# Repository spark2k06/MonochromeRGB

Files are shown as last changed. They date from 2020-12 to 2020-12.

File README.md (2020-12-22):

# MonochromeRGB

MonochromeRGB is a project to enjoy the charm of those monochrome monitors of the time but in the current video systems, those with VGA or SCART inputs. Where this product is most enjoyed is in CRT monitors, where the feeling of an old monitor is much more realistic.

https://hackaday.io/project/176201-monochromergb

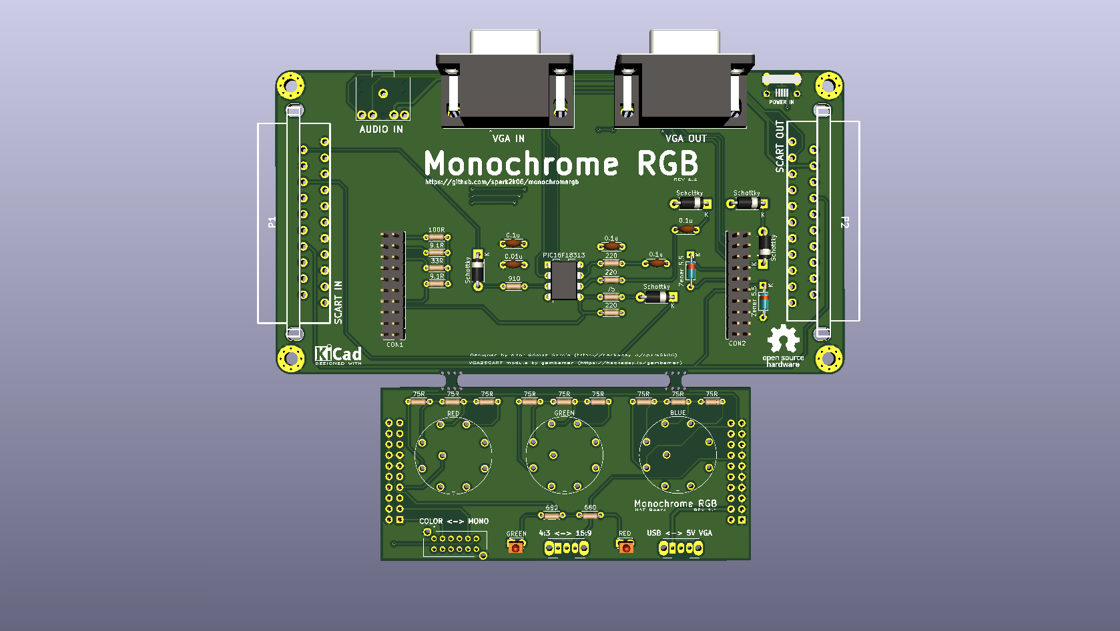
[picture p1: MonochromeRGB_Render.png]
Render


Coworked with gambaman, when integrating the VGA2SCART module: 

https://hackaday.io/project/165634-the-ultimate-vga-to-scart-adapter

open hardware facts

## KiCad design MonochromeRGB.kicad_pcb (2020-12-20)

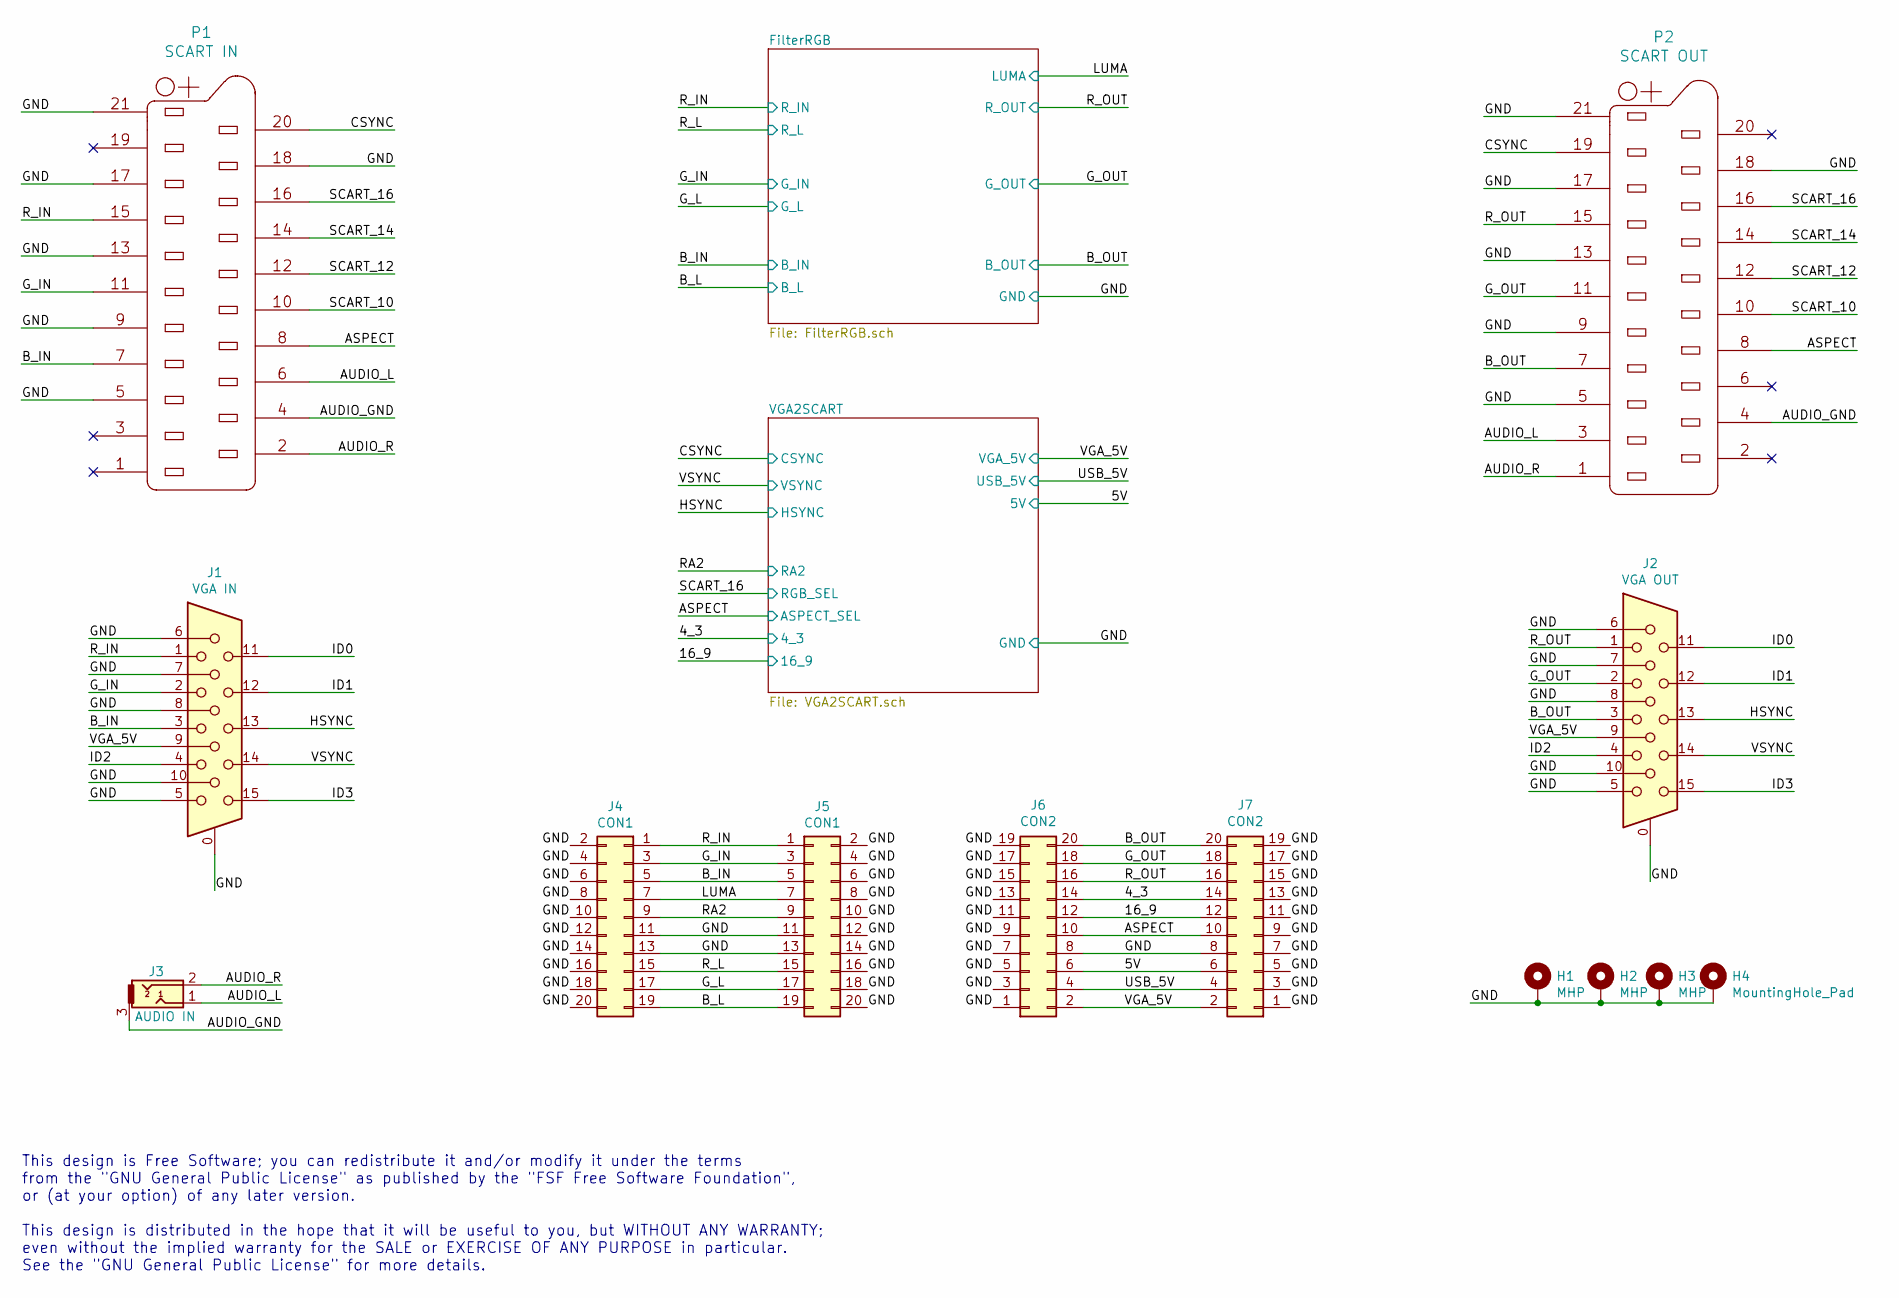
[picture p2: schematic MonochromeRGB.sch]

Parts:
H1, H2, H3: MHP; MountingHole_3.2mm_M3_Pad_Via
H4: MountingHole_Pad; MountingHole_3.2mm_M3_Pad_Via
J1: VGA IN; DSUB-15-HD_Female_Horizontal_P2.29x1.98mm_EdgePinOffset8.35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
J2: VGA OUT; DSUB-15-HD_Female_Horizontal_P2.29x1.98mm_EdgePinOffset8.35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
J3: AUDIO IN; SJ1-3523N-MvK
J4: CON1; PinHeader_2x10_P2.54mm_Vertical
J5: CON1; PinSocket_2x10_P2.54mm_Vertical
J6: CON2; PinHeader_2x10_P2.54mm_Vertical
J7: CON2; PinSocket_2x10_P2.54mm_Vertical
P1: SCART IN; SCART
P2: SCART OUT; SCART

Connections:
/4_3: J6.14, J7.14; also elsewhere on the board
/5V: J6.6, J7.6; also elsewhere on the board
/16_9: J6.12, J7.12; also elsewhere on the board
/ASPECT: J6.10, J7.10, P1.8, P2.8; also elsewhere on the board
/AUDIO_GND: J3.3, P1.4, P2.4
/AUDIO_L: J3.1, P1.6, P2.3
/AUDIO_R: J3.2, P1.2, P2.1
/B_IN: J1.3, J4.5, J5.5, P1.7; also elsewhere on the board
/B_L: J4.19, J5.19; also elsewhere on the board
/B_OUT: J2.3, J6.20, J7.20, P2.7; also elsewhere on the board
/CSYNC: P1.20, P2.19; also elsewhere on the board
/GND: H1.1, H2.1, H3.1, H4.1, J1.0, J1.5, J1.6, J1.7, J1.8, J1.10, J2.0, J2.5, J2.6, J2.7, J2.8, J2.10, J4.2, J4.4, J4.6, J4.8, J4.10, J4.11, J4.12, J4.13, J4.14, J4.16, J4.18, J4.20, J5.2, J5.4, J5.6, J5.8, J5.10, J5.11, J5.12, J5.13, J5.14, J5.16, J5.18, J5.20, J6.1, J6.3, J6.5, J6.7, J6.8, J6.9, J6.11, J6.13, J6.15, J6.17, J6.19, J7.1, J7.3, J7.5, J7.7, J7.8, J7.9, J7.11, J7.13, J7.15, J7.17, J7.19, P1.5, P1.9, P1.13, P1.17, P1.18, P1.21, P2.5, P2.9, P2.13, P2.17, P2.18, P2.21; also elsewhere on the board
/G_IN: J1.2, J4.3, J5.3, P1.11; also elsewhere on the board
/G_L: J4.17, J5.17; also elsewhere on the board
/G_OUT: J2.2, J6.18, J7.18, P2.11; also elsewhere on the board
/HSYNC: J1.13, J2.13; also elsewhere on the board
/ID0: J1.11, J2.11
/ID1: J1.12, J2.12
/ID2: J1.4, J2.4
/ID3: J1.15, J2.15
/LUMA: J4.7, J5.7; also elsewhere on the board
/RA2: J4.9, J5.9; also elsewhere on the board
/R_IN: J1.1, J4.1, J5.1, P1.15; also elsewhere on the board
/R_L: J4.15, J5.15; also elsewhere on the board
/R_OUT: J2.1, J6.16, J7.16, P2.15; also elsewhere on the board
/SCART_10: P1.10, P2.10
/SCART_12: P1.12, P2.12
/SCART_14: P1.14, P2.14
/SCART_16: P1.16, P2.16; also elsewhere on the board
/USB_5V: J6.4, J7.4; also elsewhere on the board
/VGA_5V: J1.9, J2.9, J6.2, J7.2; also elsewhere on the board
/VSYNC: J1.14, J2.14; also elsewhere on the board

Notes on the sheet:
This design is Free Software; you can redistribute it and/or modify it under the terms from the "GNU General Public License" as published by the "FSF Free Software Foundation", or (at your option) of any later version. This design is distributed in the hope that it will be useful to you, but WITHOU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

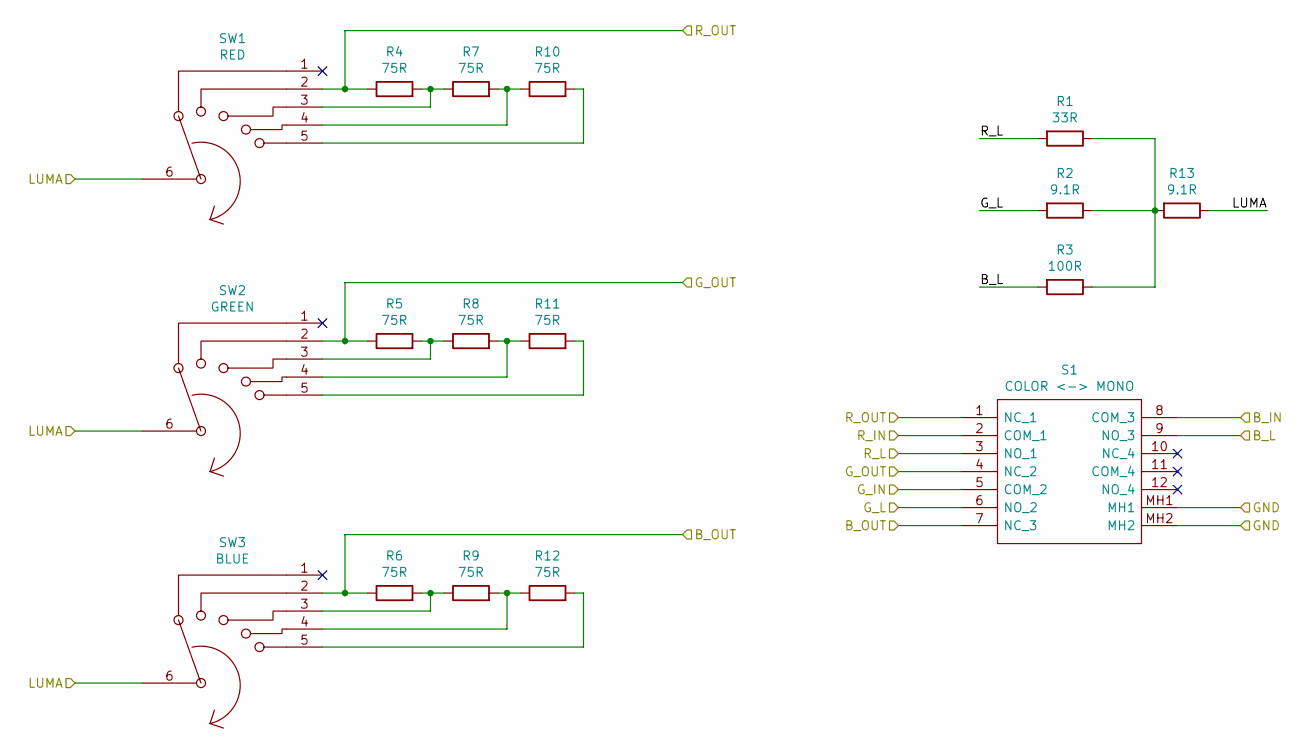
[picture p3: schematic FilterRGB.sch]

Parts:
R1: 33R; R_Axial_DIN0204_L3.6mm_D1.6mm_P5.08mm_Horizontal
R2, R13: 9.1R; R_Axial_DIN0204_L3.6mm_D1.6mm_P5.08mm_Horizontal
R3: 100R; R_Axial_DIN0204_L3.6mm_D1.6mm_P5.08mm_Horizontal
R4, R5, R6, R7, R8, R9, R10, R11, R12: 75R; R_Axial_DIN0204_L3.6mm_D1.6mm_P5.08mm_Horizontal
S1: COLOR <-> MONO; EG4208A; Mouser Part Number 612-EG4208A
SW1: RED; Rotary_Switch_1P5
SW2: GREEN; Rotary_Switch_1P5
SW3: BLUE; Rotary_Switch_1P5

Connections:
/B_IN: S1.8 (COM_3); also elsewhere on the board
/B_L: R3.2, S1.9 (NO_3); also elsewhere on the board
/B_OUT: R6.1, S1.7 (NC_3), SW3.2; also elsewhere on the board
/GND: S1.MH1, S1.MH2; also elsewhere on the board
/G_IN: S1.5 (COM_2); also elsewhere on the board
/G_L: R2.2, S1.6 (NO_2); also elsewhere on the board
/G_OUT: R5.1, S1.4 (NC_2), SW2.2; also elsewhere on the board
/LUMA: R13.1, SW1.6, SW2.6, SW3.6; also elsewhere on the board
/R_IN: S1.2 (COM_1); also elsewhere on the board
/R_L: R1.2, S1.3 (NO_1); also elsewhere on the board
/R_OUT: R4.1, S1.1 (NC_1), SW1.2; also elsewhere on the board
unnamed: R1.1, R2.1, R3.1, R13.2
unnamed: R4.2, R7.1, SW1.3
unnamed: R5.2, R8.1, SW2.3
unnamed: R6.2, R9.1, SW3.3
unnamed: R7.2, R10.1, SW1.4
unnamed: R10.2, SW1.5
unnamed: R8.2, R11.1, SW2.4
unnamed: R11.2, SW2.5
unnamed: R9.2, R12.1, SW3.4
unnamed: R12.2, SW3.5

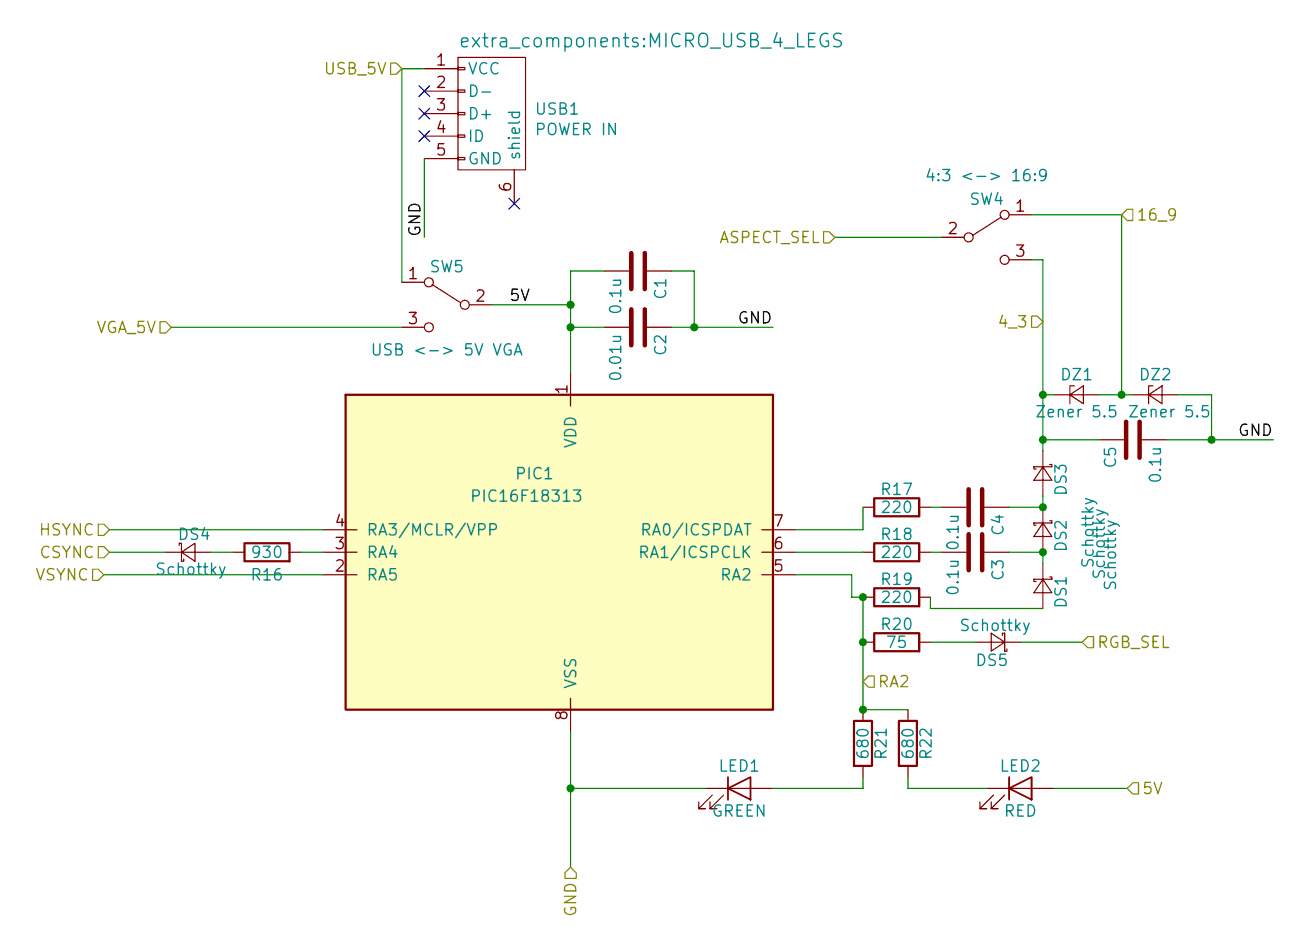
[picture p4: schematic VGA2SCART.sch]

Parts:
C1, C3, C4, C5: 0.1u; C_Disc_D4.3mm_W1.9mm_P5.00mm
C2: 0.01u; C_Disc_D4.3mm_W1.9mm_P5.00mm
DS1, DS2, DS3, DS4, DS5: Schottky; D_DO-41_SOD81_P7.62mm_Horizontal
DZ1, DZ2: Zener 5.5; D_DO-35_SOD27_P7.62mm_Horizontal
LED1: GREEN; LED_D1.8mm_W3.3mm_H2.4mm
LED2: RED; LED_D1.8mm_W3.3mm_H2.4mm
PIC1: PIC16F18313; DIP-8_W7.62mm
R16: 930; R_Axial_DIN0204_L3.6mm_D1.6mm_P5.08mm_Horizontal
R17, R18, R19: 220; R_Axial_DIN0204_L3.6mm_D1.6mm_P5.08mm_Horizontal
R20: 75; R_Axial_DIN0204_L3.6mm_D1.6mm_P5.08mm_Horizontal
R21, R22: 680; R_Axial_DIN0204_L3.6mm_D1.6mm_P5.08mm_Horizontal
SW4: 4:3 <-> 16:9; SW_CuK_OS102011MA1QN1_SPDT_Angled
SW5: USB <-> 5V VGA; SW_CuK_OS102011MA1QN1_SPDT_Angled
USB1: POWER IN; MICRO_USB_4_LEGS

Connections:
/4_3: C5.1, DS3.1 (K), DZ1.1 (K), SW4.3 (C); also elsewhere on the board
/5V: C1.2, C2.2, LED2.2 (A), PIC1.1 (VDD), SW5.2 (B); also elsewhere on the board
/16_9: DZ1.2 (A), DZ2.1 (K), SW4.1 (A); also elsewhere on the board
/ASPECT: SW4.2 (B); also elsewhere on the board
/CSYNC: DS4.1 (K); also elsewhere on the board
/GND: C1.1, C2.1, C5.2, DZ2.2 (A), LED1.1 (K), PIC1.8 (VSS), USB1.5 (GND); also elsewhere on the board
/HSYNC: PIC1.4 (RA3/MCLR/VPP); also elsewhere on the board
/RA2: PIC1.5 (RA2), R19.1, R20.1, R21.1, R22.1; also elsewhere on the board
/SCART_16: DS5.1 (K); also elsewhere on the board
/USB_5V: SW5.1 (A), USB1.1 (VCC); also elsewhere on the board
/VGA_5V: SW5.3 (C); also elsewhere on the board
/VSYNC: PIC1.2 (RA5); also elsewhere on the board
unnamed: C3.1, DS1.1 (K), DS2.2 (A)
unnamed: C3.2, R18.2
unnamed: C4.1, DS2.1 (K), DS3.2 (A)
unnamed: C4.2, R17.2
unnamed: DS1.2 (A), R19.2
unnamed: DS4.2 (A), R16.1
unnamed: DS5.2 (A), R20.2
unnamed: LED1.2 (A), R21.2
unnamed: LED2.1 (K), R22.2
unnamed: PIC1.3 (RA4), R16.2
unnamed: PIC1.6 (RA1/ICSPCLK), R18.1
unnamed: PIC1.7 (RA0/ICSPDAT), R17.1

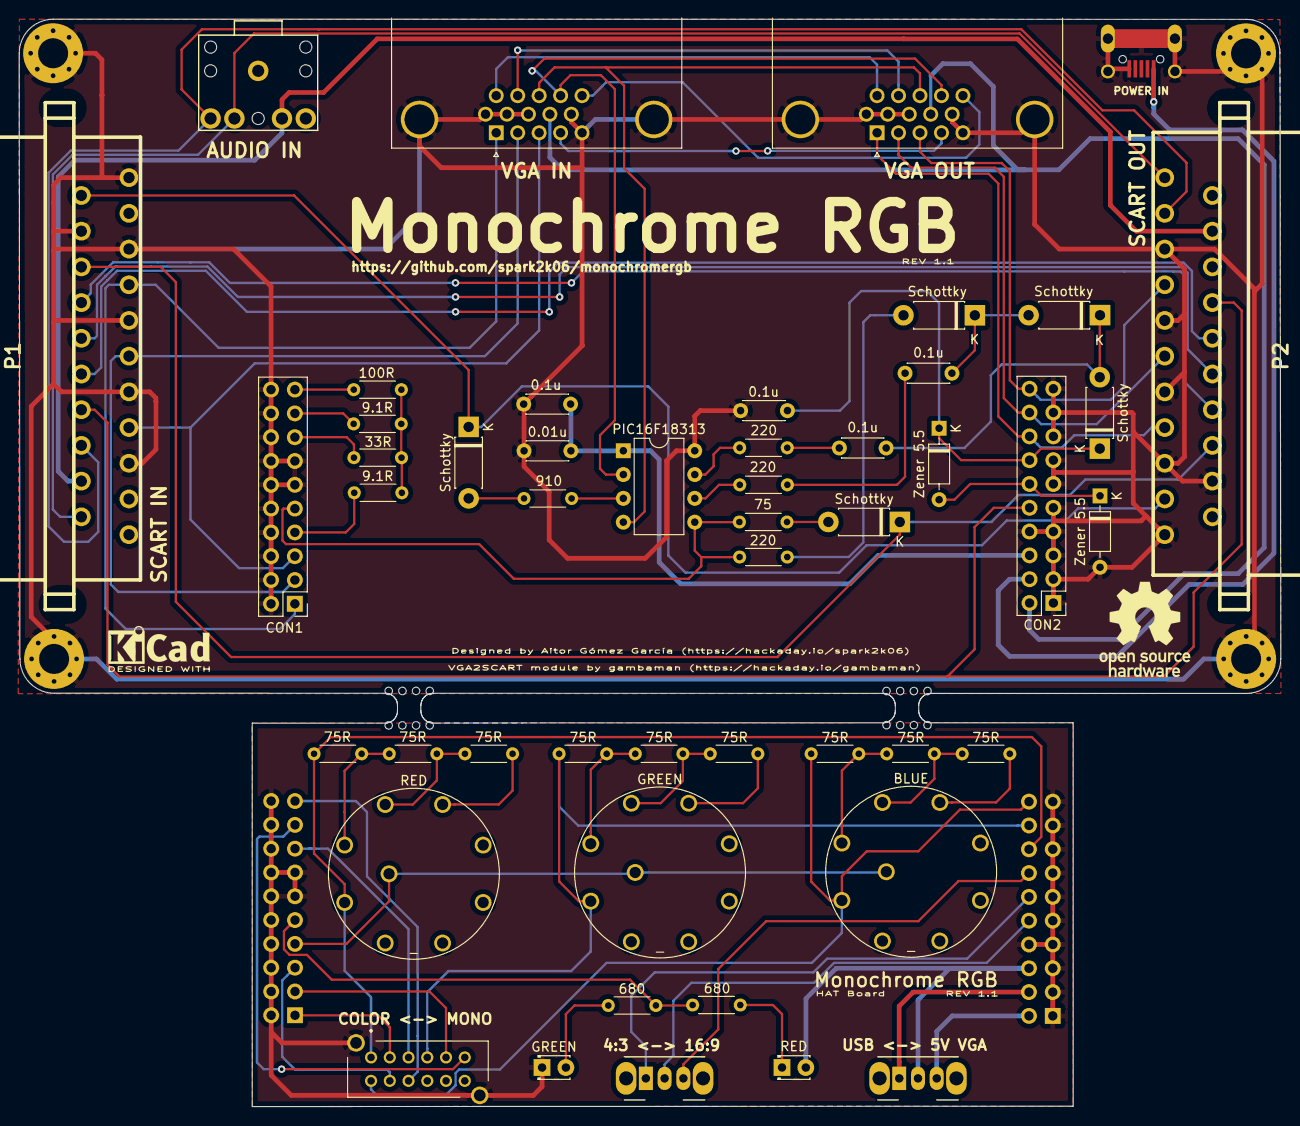
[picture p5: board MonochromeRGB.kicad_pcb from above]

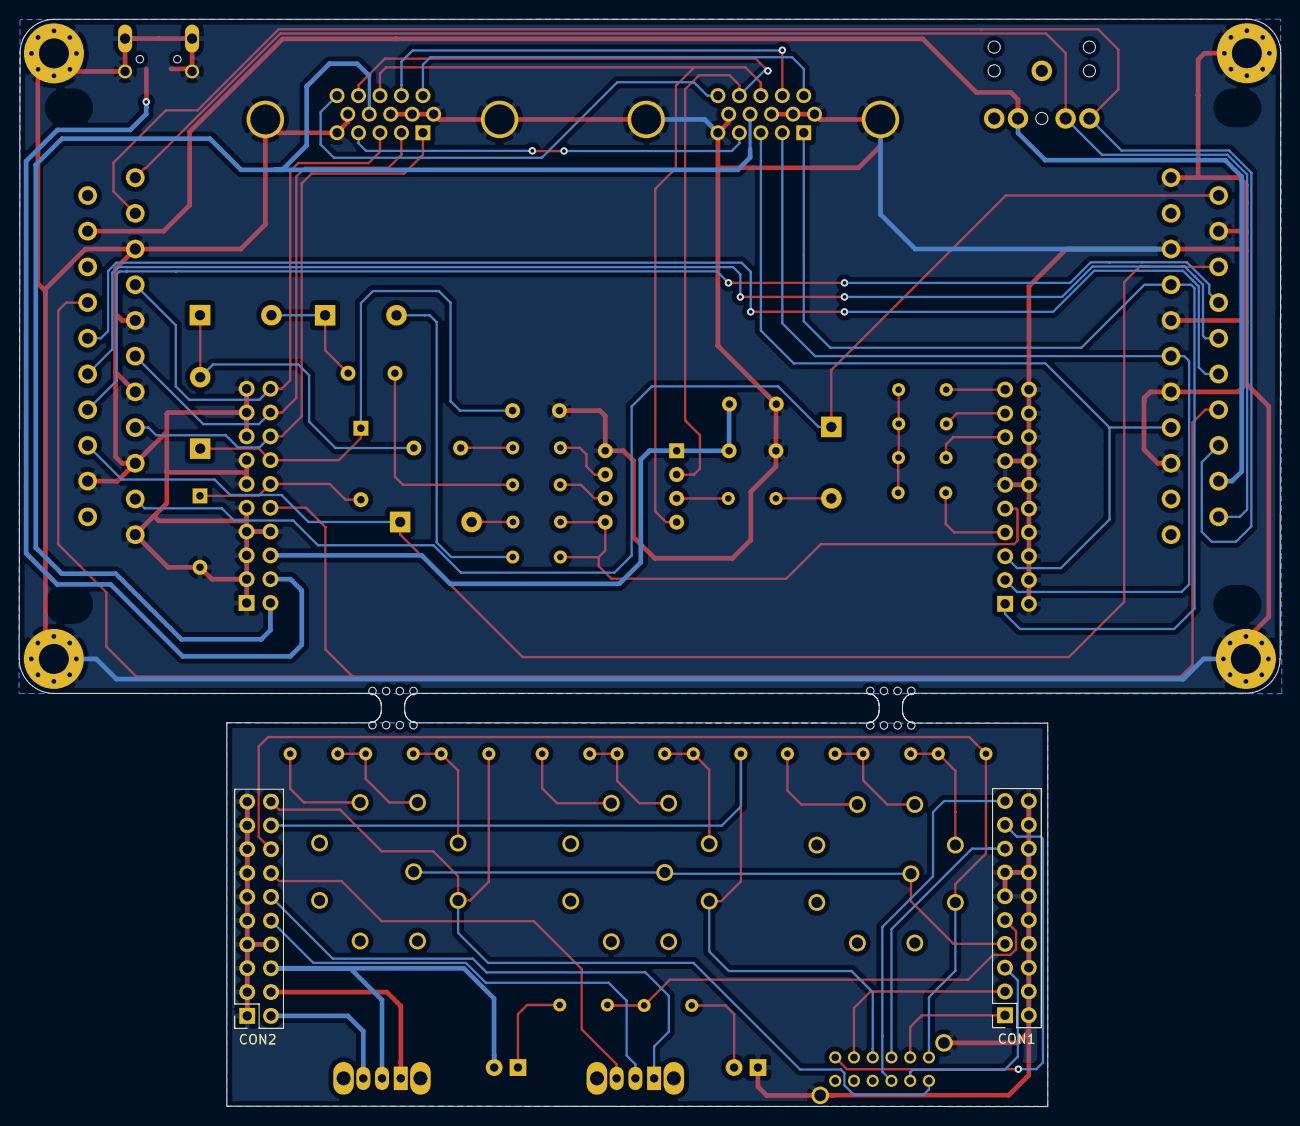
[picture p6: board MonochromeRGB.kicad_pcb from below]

Board: 2 copper layers, 134.6 x 116.0 mm, 55 parts (2 on the bottom side), 54 nets.

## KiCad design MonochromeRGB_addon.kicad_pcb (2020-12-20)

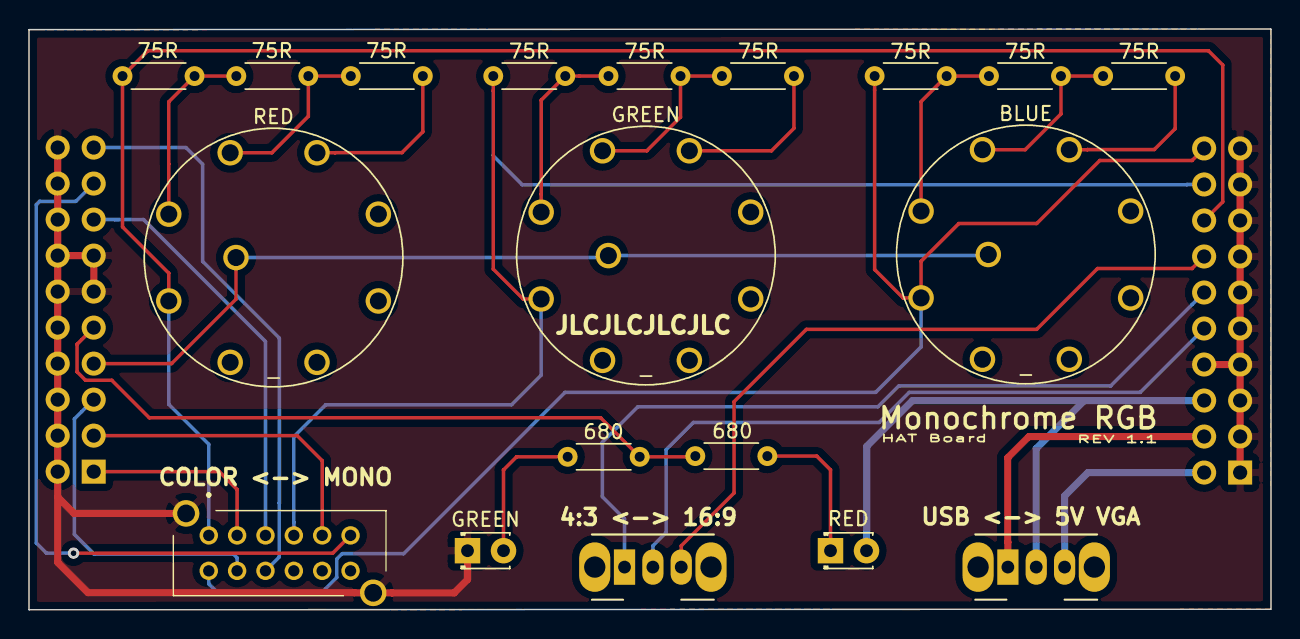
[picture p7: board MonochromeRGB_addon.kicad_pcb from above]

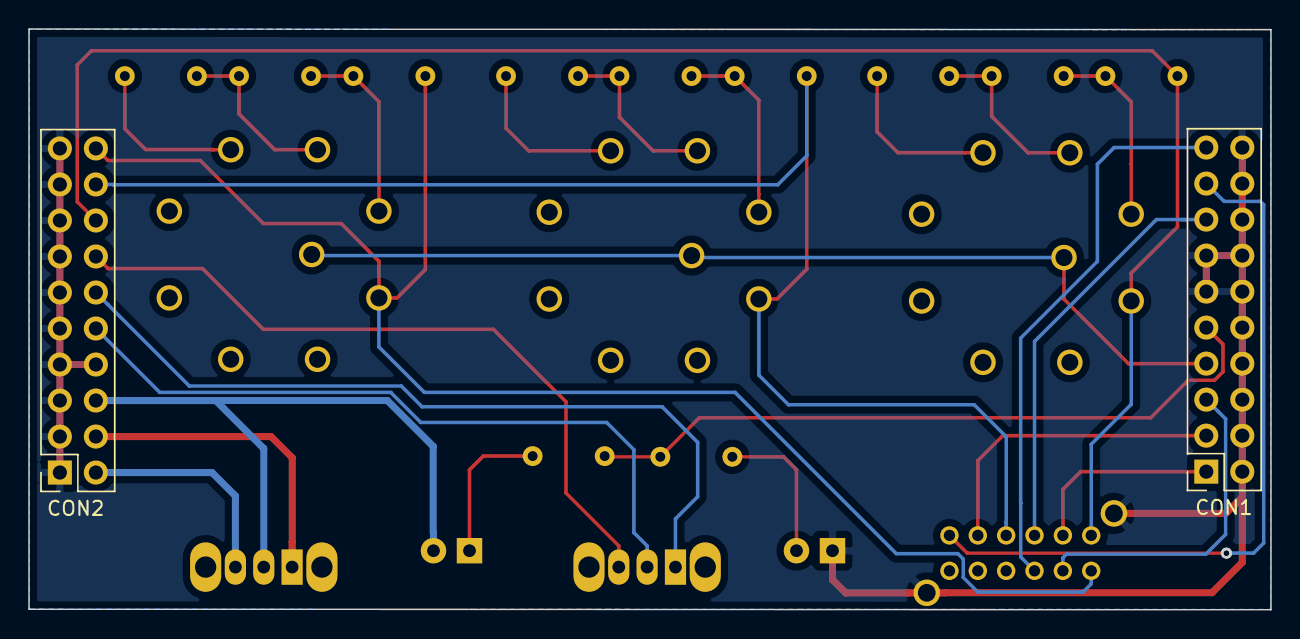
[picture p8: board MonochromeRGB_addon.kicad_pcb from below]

Board: 2 copper layers, 87.6 x 41.0 mm, 21 parts (2 on the bottom side), 29 nets.

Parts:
J5: CON1; PinSocket_2x10_P2.54mm_Vertical
J7: CON2; PinSocket_2x10_P2.54mm_Vertical
LED1: GREEN; LED_D1.8mm_W3.3mm_H2.4mm
LED2: RED; LED_D1.8mm_W3.3mm_H2.4mm
R4, R5, R6, R7, R8, R9, R10, R11, R12: 75R; R_Axial_DIN0204_L3.6mm_D1.6mm_P5.08mm_Horizontal
R21, R22: 680; R_Axial_DIN0204_L3.6mm_D1.6mm_P5.08mm_Horizontal
S1: COLOR <-> MONO; EG4208A
SW1: RED; Rotary_Switch_1P5
SW2: GREEN; Rotary_Switch_1P5
SW3: BLUE; Rotary_Switch_1P5
SW4: 4:3 <-> 16:9; SW_CuK_OS102011MA1QN1_SPDT_Angled
SW5: USB <-> 5V VGA; SW_CuK_OS102011MA1QN1_SPDT_Angled

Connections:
/4_3: J7.14, SW4.3
/5V: J7.6, LED2.2, SW5.2
/16_9: J7.12, SW4.1
/ASPECT: J7.10, SW4.2
/B_IN: J5.5, S1.8
/B_L: J5.19, S1.9
/B_OUT: J7.20, R6.1, S1.7, SW3.2
/GND: J5.2, J5.4, J5.6, J5.8, J5.10, J5.11, J5.12, J5.13, J5.14, J5.16, J5.18, J5.20, J7.1, J7.3, J7.5, J7.7, J7.8, J7.9, J7.11, J7.13, J7.15, J7.17, J7.19, LED1.1, S1.MH1, S1.MH2
/G_IN: J5.3, S1.5
/G_L: J5.17, S1.6
/G_OUT: J7.18, R5.1, S1.4, SW2.2
/LUMA: J5.7, SW1.6, SW2.6, SW3.6
/RA2: J5.9, R21.1, R22.1
/R_IN: J5.1, S1.2
/R_L: J5.15, S1.3
/R_OUT: J7.16, R4.1, S1.1, SW1.2
/USB_5V: J7.4, SW5.1
/VGA_5V: J7.2, SW5.3
unnamed: LED1.2, R21.2
unnamed: LED2.1, R22.2
unnamed: R4.2, R7.1, SW1.3
unnamed: R5.2, R8.1, SW2.3
unnamed: R6.2, R9.1, SW3.3
unnamed: R7.2, R10.1, SW1.4
unnamed: R10.2, SW1.5
unnamed: R8.2, R11.1, SW2.4
unnamed: R11.2, SW2.5
unnamed: R9.2, R12.1, SW3.4
unnamed: R12.2, SW3.5

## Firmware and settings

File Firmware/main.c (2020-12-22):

/* VGA sync to SCART composite video sync generator
 * Copyright (C) 2019 David Guerrero
 *
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
 * THE SOFTWARE IS PROVIDED "AS IS", WITHOUT WARRANTY OF ANY KIND, EXPRESS OR
 * IMPLIED, INCLUDING BUT NOT LIMITED TO THE WARRANTIES OF MERCHANTABILITY,
 * FITNESS FOR A PARTICULAR PURPOSE AND NONINFRINGEMENT. IN NO EVENT SHALL THE
 * AUTHORS OR COPYRIGHT HOLDERS BE LIABLE FOR ANY CLAIM, DAMAGES OR OTHER
 * LIABILITY, WHETHER IN AN ACTION OF CONTRACT, TORT OR OTHERWISE, ARISING FROM,
 * OUT OF OR IN CONNECTION WITH THE SOFTWARE OR THE USE OR OTHER DEALINGS IN
 * THE SOFTWARE.
 */

#include <pic.h>
#include <stdint.h>

// CONFIG1
#pragma config FEXTOSC = OFF // FEXTOSC External Oscillator mode Selection bits (Oscillator not enabled)
#pragma config RSTOSC = HFINT32 // Power-up default value for COSC bits (HFINTOSC with 2x PLL (32MHz))
#pragma config CLKOUTEN = OFF // Clock Out Enable bit (CLKOUT function is enabled; FOSC/4 clock appears at OSC2)
#pragma config CSWEN = ON // Clock Switch Enable bit (Writing to NOSC and NDIV is allowed)
#pragma config FCMEN = ON // Fail-Safe Clock Monitor Enable (Fail-Safe Clock Monitor is enabled)

// CONFIG2
#pragma config MCLRE = OFF // Master Clear Enable bit (MCLR/VPP pin function is digital input; MCLR internally disabled; Weak pull-up under control of port pin's WPU control bit.)
#pragma config PWRTE = ON // Power-up Timer Enable bit (PWRT enabled)
#pragma config WDTE = OFF // Watchdog Timer Enable bits (WDT disabled; SWDTEN is ignored)
#pragma config LPBOREN = OFF // Low-power BOR enable bit (ULPBOR disabled)
#pragma config BOREN = ON // Brown-out Reset Enable bits (Brown-out Reset enabled, SBOREN bit ignored)
#pragma config BORV = HIGH // Brown-out Reset Voltage selection bit (Brown-out voltage (Vbor) set to 2.45V)
#pragma config PPS1WAY = OFF // PPSLOCK bit One-Way Set Enable bit (The PPSLOCK bit can be cleared and set only once; PPS registers remain locked after one clear/set cycle)
#pragma config STVREN = ON // Stack Overflow/Underflow Reset Enable bit (Stack Overflow or Underflow will cause a Reset)
#pragma config DEBUG = OFF // Debugger enable bit (Background debugger disabled)


// CONFIG3
#pragma config WRT = OFF // User NVM self-write protection bits (Write protection off)
#pragma config LVP = OFF // Low Voltage Programming Enable bit (Low voltage programming enabled. MCLR/VPP pin function is MCLR. MCLRE configuration bit is ignored.)

// CONFIG4
#pragma config CP = OFF // User NVM Program Memory Code Protection bit (User NVM code protection disabled)
#pragma config CPD = OFF // Data NVM Memory Code Protection bit (Data NVM code protection disabled)

#define _XTAL_FREQ 32000000 //system clock frequency in hertzs
#define wave_FREQ 160000 //desired output wave frequency in hertzs
#define NCO_increment ((((uint32_t)wave_FREQ)<<11)/15625)//NCO clock will be HFINTOSC (16 MHz))
#define hsync_FREQ  15734 //Hsync nominal frequency in hertzs
#define hsync_normal_value LC1G3POL
#define vsync_pulsed_value LC1G1POL
#define hsync_value RA3
#define hsync_RA_number 3
#define vsync_value RA5
#define vsync_RA_number 5
#define enable RA2
#define enable_RA_number 2
#define cynscPPS RA4PPS
#define csync_RA_number 4
#define countdown_duration 740

void main(void)
{
    PORTA=0;
    TRISA=(1 << vsync_RA_number) | (1 << hsync_RA_number); //vsync and hsync input, everything else output
    ANSELA=0; //no analog inputs
    
    NCO1CLK=0;//NCO input clock is FINTOSC (16 MHz)
    NCO1INCU=NCO_increment>>16;
    NCO1INCH=NCO_increment>>8;
    NCO1INCL=NCO_increment;
    NCO1CON=0b10000000;//NCO enabled in fixed duty cycle mode
    
    CWG1DAT=0b00001001;//CWG clock source is NCO
    CWG1AS0=0b01101000;//Auto-Restart of CWG enabled. All waves=0 when disabled
    CWG1AS1=1;//CWG shutdowns only when pin CWG1PPS (enable signal) is low
    CWG1PPS=enable_RA_number;//CWG1PPS=enable signal
    RA0PPS=0b00001000;//RA0 pin is wave A
    RA1PPS=0b00001001;//RA1 pin is wave B
    CWG1CON0=0b10000100;//enable CWG in half-bridge mode.
    
    CLCIN0PPS=vsync_RA_number;//CLCIN0=vsync
    CLCIN1PPS=hsync_RA_number;//CLCIN1=hsync
    CLC1SEL0=0b00000000; //lc1d1T=CLCIN0 (vsync)
    CLC1SEL1=0b00000001; //lc1d2T=CLCIN1 (hsync)
    CLC1GLS0=0b00000010; //so lc1g1 will be lc1d1T=CLCIN0 (vsync)
    CLC1GLS1=0;          //so lc1g2 will be 0
    CLC1GLS2=0b00001000; //so lc1g3 will be lc1d3T=CLCIN1 (hsync)
    CLC1GLS3=0;          //so lc1g4 will be 0
    CLC1POL=0;           //nothing is inverted for now
    cynscPPS=0b00000100; //csync will be driven by the the output of the logic cell CLC1
    CLC1CON=0b10000001; //enable CLC output, disable CLC interrupts, set CLC functional mode at OR-XOR
    INTPPS=hsync_RA_number;//external interrupt source is hsync
    
    //tmr2 will be used to measure the period of hsync. Note that tmr2 prescaler source fequency is _XTAL_FREQ/4
    PR2=11*_XTAL_FREQ/hsync_FREQ/10/16;//set PR2 to the maximun acceptable hsync period
    PIE1bits.TMR2IE=1;//enables tmr2 match interrupt to detect if the period is too high. Does not matter if executed at the begining
    TMR2=0;
    T2CON=0b00000101;//activates tmr2, sets postcaler to 1:1 and prescaler to 1:4
    INTCON=0b11010000;//Enable global interrupts and peripheral interrupts (for tmr2 comparation match), external interrupt at the falling edge of hsync
    PIE0=0b00000001;//Enable external interrupt
    while(1);
}

__interrupt() void isr(void)
{  
    static uint16_t activation_countdown=countdown_duration;
    static uint16_t vsync_highs=0;
    PIR0bits.INTF=0;//clear external interrupt flag. Does not matter if this is being executed because of TMR2 overflow
    uint8_t hsync_period=TMR2;
    TMR2=0;
    __delay_us(300000/hsync_FREQ);//wait for a 30% of the nominal period to make sure hsync is not pulsed before reading it
    CLC1POLbits.hsync_normal_value=PORTAbits.hsync_value;//this has no efect if the previos value is the same, otherwise reconfigure the CLC for the correct polarity of the hsync pulses
    /////now check if the input sync signals are OK
    if( 
            hsync_period<=9*_XTAL_FREQ/hsync_FREQ/10/16 //hsync frequency is too high
        ||  PIR1bits.TMR2IF //hsync frequency is too low
        ||  (activation_countdown==0 && (vsync_highs==0 || vsync_highs==countdown_duration))//vsync is not changing
      )//something is wrong. Csync must be disabled
        {   
            CLC1CONbits.LC1EN=0;//fix CLC output to 0
            PORTAbits.enable=0;//set the enable output signal to 0
            activation_countdown=countdown_duration;
            vsync_highs=0;
        }
    /////now enable csync at the end of the countdown check if the input sync signals are OK
    if(activation_countdown)
        {//This is executed countdown_duration times before activation
            vsync_highs+=PORTAbits.vsync_value;//count the number of times vsync is high
            activation_countdown--;
        }
    else
        {//end of countdown reached. Csync must be enabled
            CLC1POLbits.vsync_pulsed_value= vsync_highs<countdown_duration/2;//inverts vsync if necessary
            CLC1CONbits.LC1EN=1;//so the CLC output can change
            PORTAbits.enable=1;//set the enable output signal to 1
            activation_countdown=countdown_duration;//Vsync must be measured periodically
            vsync_highs=0;                          //because the video mode can change
        }
    PIR1bits.TMR2IF=0;
}
